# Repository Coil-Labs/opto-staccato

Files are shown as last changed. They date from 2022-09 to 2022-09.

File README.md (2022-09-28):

# opto-staccato

## Introduction
This is a pair of circuit boards (PCBs), known as the Opto-Staccato Controller and Receiver, which are a mains frequency synchronized interrupter for Tesla coils, primarily vacuum tube Tesla coils (VTTCs).

This circuit is based on the original Staccato Controller, created by Steve Ward https://www.stevehv.4hv.org/staccato.htm

This circuit is featured on the Coil Labs YouTube channel and is used to interrupt a large VTTC (https://youtu.be/IDOrxT_r8TY). This project was sponsored in part by PCBgogo (https://www.pcbgogo.com/), who provided the PCBs for this video.

The KiCad source files for both boards are available in this repository and the gerber files for both boards are available as .zip files in the Releases.

## Description

The Controller PCB detects the mains frequency zero crossing and then sends a pulse to the Receiver (with a controllable delay based on potentiometer RV1), signaling when to let the Tesla coil primary circuit to begin conducting. This signal is sent over a fiber optic link to protect the user from coming into contact with high voltage and enabling them to maintain a safe distance from the Tesla coil. The other controllable parameter (set by potentiometer RV2) of the Controller is the interrupter hold-off time, which enables the Tesla coil to be driven at integer factors of the mains frequency (e.g., 60 Hz, 30 Hz, 15 Hz, etc. in North America).

## Safety
WARNING! High voltage electricity and Tesla coils are dangerous and should not be handled or operated by anyone other than trained experts! 

## Usage
Jumpers J5 and J6 on the Controller and J7 and J8 on the Receiver enable using the PCBs in either 120V or 240V mains regions. Place two jumpers across pins 1 and 2 of both jumpers for 120V use or a single jumper across pin 2 of the two jumpers for 240V use, as indicated on the silk screen.

On the Controller, switch SW1 is the "phase-select" choosing to trigger the circuit on either the rising or falling mains zero crossing. Switch Sw2 is the "output-enable" switch, allowing the user to control when the Tesla coil interrupter is "turned on". Switch Sw3 selects the source of the signal being sent out via the fiber optic link; either the Staccato signal, "always on" for continuous wave operation, or an optional external 0-12V digital signal that can be provided via screw terminal J2.

The SCR or TRIAC used for Staccato operation is not included on the Receiver PCB as the choice of this component is specific to each Tesla coil. A screw terminal block J4 is provided to connect to the gate and cathode terminals for triggering. The selection of resistor R22 may need to be changed, depending on the gate voltage and current requirements of the SCR/TRIAC being used.

The fiber optic transmitter and receiver use standard 1000um core, 2.2mm jacket plastic fiber cable. The fuses are 500mA, 250V, fast blow, glass cartridge, 5mm x 20mm.

## License
These design files are published under the CERN Open Hardware License Version 2 - Weakly Reciprocal variant (CERN-OHL-W). Read more here (https://cern.ch/cern-ohl).

This is a copyleft, share-alike, open-source license. This means that you are free to redistribute, modify, or make derivatives these designs, and even commercialize them. But you MUST keep the redistributed, modified, or derivative designs open-source and under this or a compatible license. You CANNOT make modified or derivative designs proprietary; they MUST be kept open-source. This is different than a "permissive" open-source license, where you can make modifications or derivatives proprietary and then commercialize and profit off of your proprietary modification. You are absolutely free to commercialize and profit from modifications of this design, however, it must remain open-source and accessible to the public. Copyleft, share-alike is a philosophy. Scientific and engineering knowledge should not be kept as trade secrets and locked down under patents, owned by the wealthy, to only benefit the wealthy. Knowledge should be freely shared, always. Publishing scientific and engineering works under copyleft, share-alike licenses helps to create a more fair and democratic future where the hoarding of trade secrets is not a way to gain a competitive advantage. Please consider publishing your own works under such a license.

## Controller Schematic
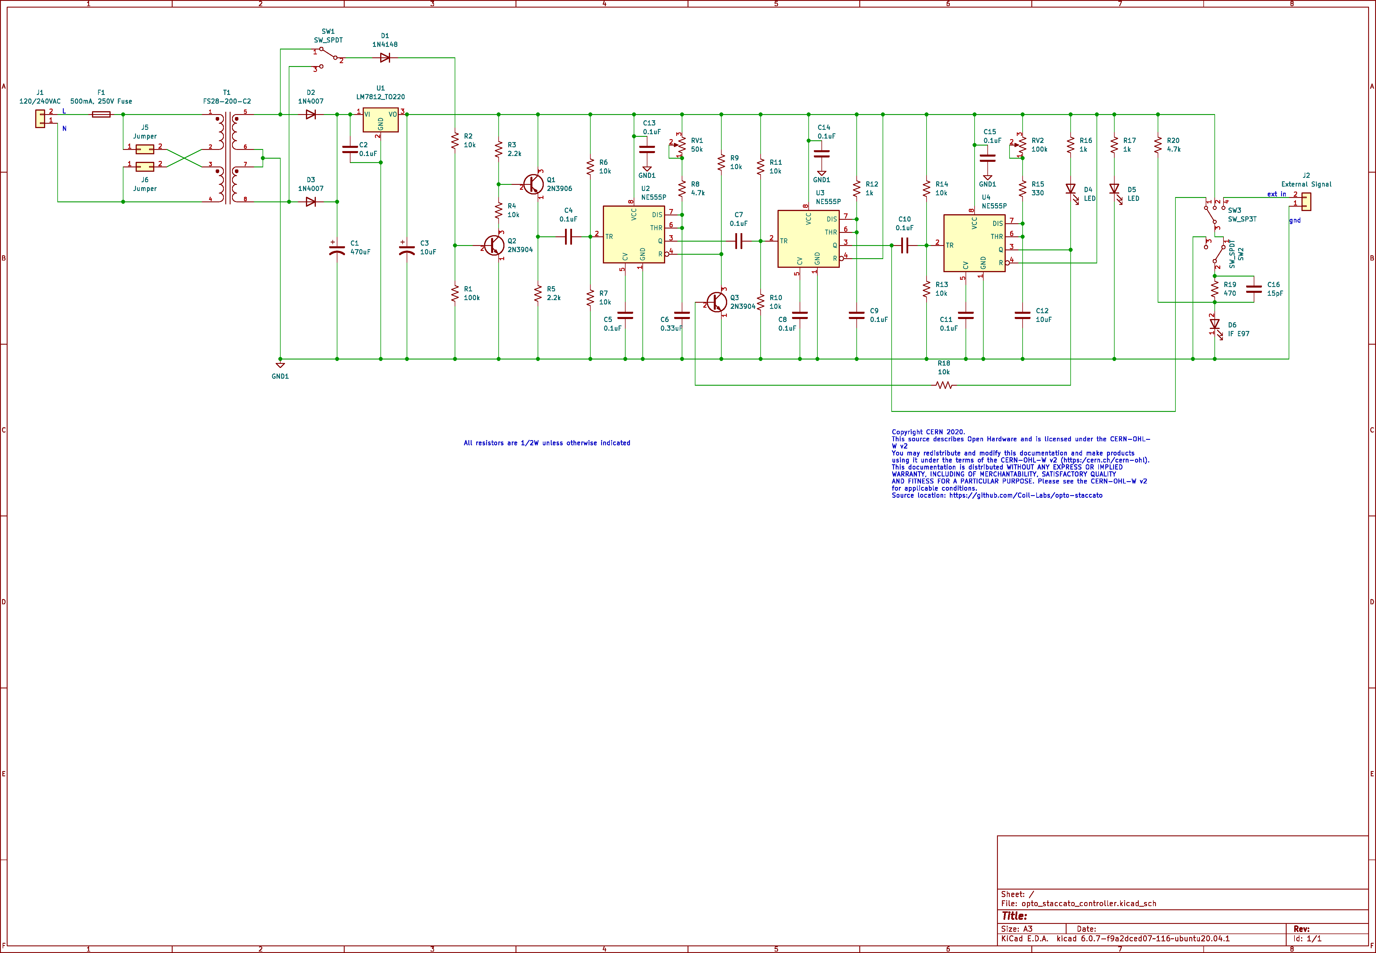
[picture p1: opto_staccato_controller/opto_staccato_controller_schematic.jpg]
Controller Schematic


## Receiver Schematic
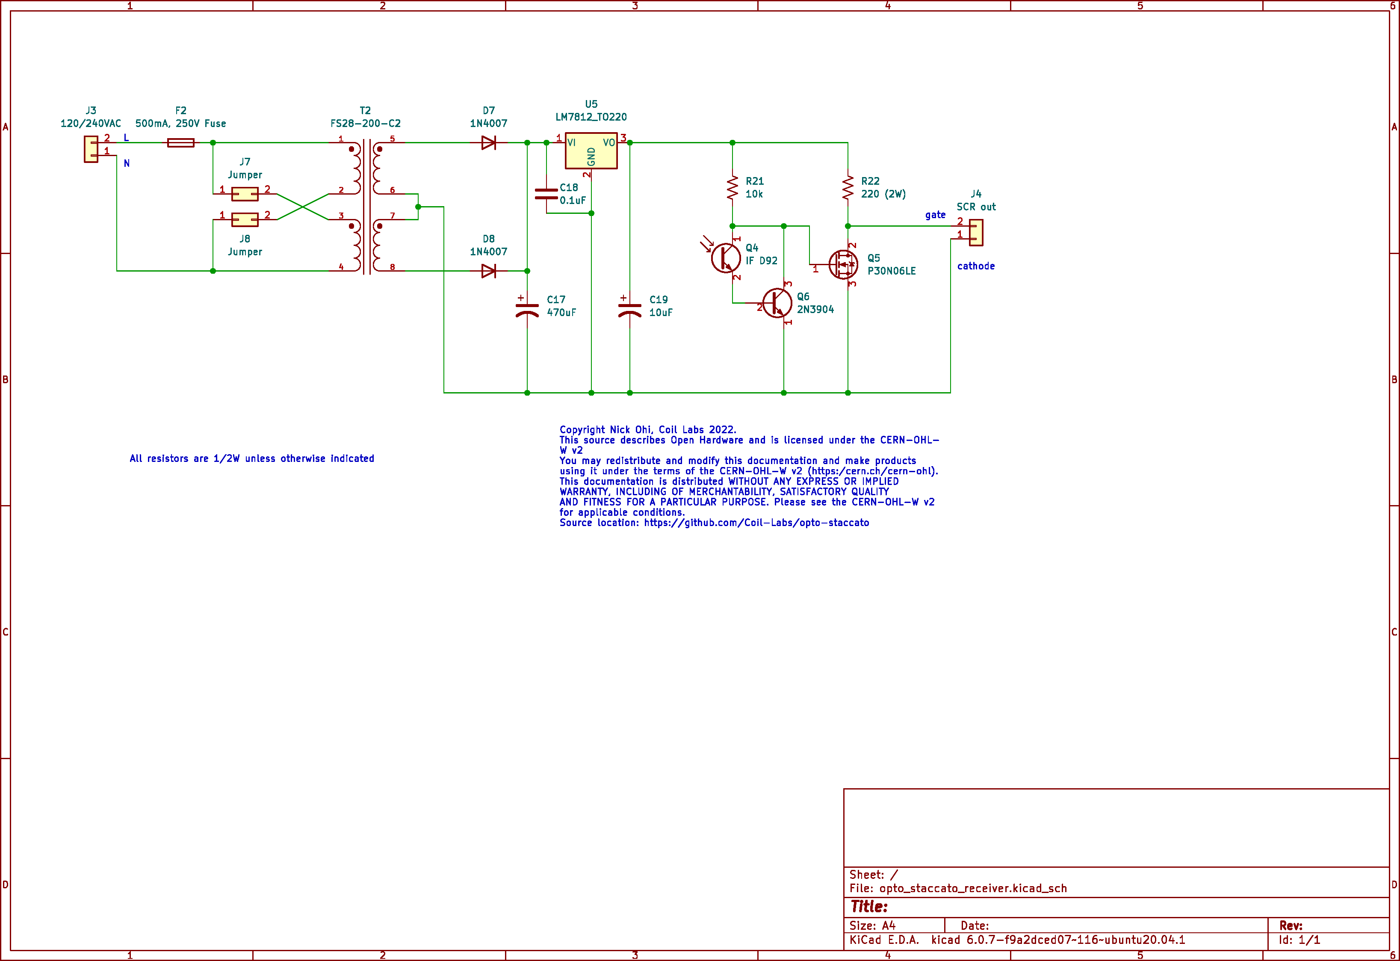
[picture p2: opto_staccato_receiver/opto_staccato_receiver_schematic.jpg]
Receiver Schematic


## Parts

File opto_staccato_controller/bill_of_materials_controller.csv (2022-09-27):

Date: | Mon 26 Sep 2022 07:49:17 PM EDT
Tool: | Eeschema 6.0.7-f9a2dced07~116~ubuntu20.04.1
Component Count: | 60
Individual Components:
Item | Qty | Reference(s) | Value | LibPart | Footprint | Datasheet | MANUFACTURER | STANDARD | Spice_Lib_File | Spice_Model | Spice_Netlist_Enabled | Spice_Primitive
 |  | C1 | 470uF | Device:C_Polarized_US | Capacitor_THT:CP_Radial_D10.0mm_P5.00mm | ~ |  |  |  | 470u | Y | C
 |  | C2 | 0.1uF | Device:C | Capacitor_THT:C_Disc_D4.7mm_W2.5mm_P5.00mm | ~ |  |  |  | 0.1u | Y | C
 |  | C3 | 10uF | Device:C_Polarized_US | Capacitor_THT:CP_Radial_D5.0mm_P2.00mm | ~ |  |  |  | 10u | Y | C
 |  | C4 | 0.1uF | Device:C | Capacitor_THT:C_Disc_D4.7mm_W2.5mm_P5.00mm | ~ |  |  |  | 0.1u | Y | C
 |  | C5 | 0.1uF | Device:C | Capacitor_THT:C_Disc_D4.7mm_W2.5mm_P5.00mm | ~
 |  | C6 | 0.33uF | Device:C | Capacitor_THT:C_Disc_D6.0mm_W4.4mm_P5.00mm | ~
 |  | C7 | 0.1uF | Device:C | Capacitor_THT:C_Disc_D4.7mm_W2.5mm_P5.00mm | ~
 |  | C8 | 0.1uF | Device:C | Capacitor_THT:C_Disc_D4.7mm_W2.5mm_P5.00mm | ~ |  |  |  | 0.1u | Y | C
 |  | C9 | 0.1uF | Device:C | Capacitor_THT:C_Disc_D4.7mm_W2.5mm_P5.00mm | ~ |  |  |  | 0.2u | Y | C
 |  | C10 | 0.1uF | Device:C | Capacitor_THT:C_Disc_D4.7mm_W2.5mm_P5.00mm | ~ |  |  |  | 0.001u | Y | C
 |  | C11 | 0.1uF | Device:C | Capacitor_THT:C_Disc_D4.7mm_W2.5mm_P5.00mm | ~ |  |  |  | 0.1u | Y | C
 |  | C12 | 10uF | Device:C | Capacitor_THT:C_Disc_D5.1mm_W3.2mm_P5.00mm | ~ |  |  |  | 10u | Y | C
 |  | C13 | 0.1uF | Device:C | Capacitor_THT:C_Disc_D4.7mm_W2.5mm_P5.00mm | ~
 |  | C14 | 0.1uF | Device:C | Capacitor_THT:C_Disc_D4.7mm_W2.5mm_P5.00mm | ~
 |  | C15 | 0.1uF | Device:C | Capacitor_THT:C_Disc_D4.7mm_W2.5mm_P5.00mm | ~
 |  | C16 | 15pF | Device:C | Capacitor_THT:C_Disc_D4.7mm_W2.5mm_P5.00mm | ~
 |  | D1 | 1N4148 | Diode:1N4007 | Diode_THT:D_DO-35_SOD27_P7.62mm_Horizontal | http://www.vishay.com/docs/88503/1n4001.pdf |  |  |  | 1N4007 | Y | D
 |  | D2 | 1N4007 | Diode:1N4007 | Diode_THT:D_DO-41_SOD81_P10.16mm_Horizontal | http://www.vishay.com/docs/88503/1n4001.pdf |  |  |  | 1N4007 | Y | D
 |  | D3 | 1N4007 | Diode:1N4007 | Diode_THT:D_DO-41_SOD81_P10.16mm_Horizontal | http://www.vishay.com/docs/88503/1n4001.pdf |  |  |  | 1N4007 | Y | D
 |  | D4 | LED | Device:LED | LED_THT:LED_D5.0mm_Clear | ~ |  |  |  | LED_GENERAL | Y | D
 |  | D5 | LED | Device:LED | LED_THT:LED_D5.0mm_Clear | ~ |  |  |  | LED_GENERAL | Y | D
 |  | D6 | IF E97 | :LED_1 | IF-E91A:IF-E91A | ~
 |  | F1 | 500mA, 250V Fuse | Device:Fuse | 0PTF0078P:0PTF0078P | ~
 |  | J1 | 120/240VAC | Connector_Generic:Conn_01x02 | Connector_Wire:SolderWire-1sqmm_1x02_P5.4mm_D1.4mm_OD2.7mm | ~
 |  | J2 | External Signal | Connector_Generic:Conn_01x02 | TB007-508-02GR:CUI_TB007-508-02GR | ~
 |  | J5 | Jumper | Connector_Generic:Conn_02x01 | Connector_PinHeader_2.54mm:PinHeader_2x01_P2.54mm_Vertical | ~
 |  | J6 | Jumper | Connector_Generic:Conn_02x01 | Connector_PinHeader_2.54mm:PinHeader_2x01_P2.54mm_Vertical | ~
 |  | Q1 | 2N3906 | Transistor_BJT:2N3906 | Package_TO_SOT_THT:TO-92_Inline | https://www.onsemi.com/pub/Collateral/2N3906-D.PDF |  |  |  | 2N3906 | Y | Q
 |  | Q2 | 2N3904 | Transistor_BJT:2N3904 | Package_TO_SOT_THT:TO-92_Inline | https://www.onsemi.com/pub/Collateral/2N3903-D.PDF |  |  |  | 2N3904 | Y | Q
 |  | Q3 | 2N3904 | Transistor_BJT:2N3904 | Package_TO_SOT_THT:TO-92_Inline | https://www.onsemi.com/pub/Collateral/2N3903-D.PDF |  |  |  | 2N3904 | Y | Q
 |  | R1 | 100k | Device:R_US | Resistor_THT:R_Axial_DIN0309_L9.0mm_D3.2mm_P12.70mm_Horizontal | ~ |  |  |  | 100k | Y | R
 |  | R2 | 10k | Device:R_US | Resistor_THT:R_Axial_DIN0309_L9.0mm_D3.2mm_P12.70mm_Horizontal | ~ |  |  |  | 10k | Y | R
 |  | R3 | 2.2k | Device:R_US | Resistor_THT:R_Axial_DIN0309_L9.0mm_D3.2mm_P12.70mm_Horizontal | ~ |  |  |  | 2.2k | Y | R
 |  | R4 | 10k | Device:R_US | Resistor_THT:R_Axial_DIN0309_L9.0mm_D3.2mm_P12.70mm_Horizontal | ~ |  |  |  | 10k | Y | R
 |  | R5 | 2.2k | Device:R_US | Resistor_THT:R_Axial_DIN0309_L9.0mm_D3.2mm_P12.70mm_Horizontal | ~ |  |  |  | 2.2k | Y | R
 |  | R6 | 10k | Device:R_US | Resistor_THT:R_Axial_DIN0309_L9.0mm_D3.2mm_P12.70mm_Horizontal | ~ |  |  |  | 100k | Y | R
 |  | R7 | 10k | Device:R_US | Resistor_THT:R_Axial_DIN0309_L9.0mm_D3.2mm_P12.70mm_Horizontal | ~ |  |  |  | 100k | Y | R
 |  | R8 | 4.7k | Device:R_US | Resistor_THT:R_Axial_DIN0309_L9.0mm_D3.2mm_P12.70mm_Horizontal | ~
 |  | R9 | 10k | Device:R_US | Resistor_THT:R_Axial_DIN0309_L9.0mm_D3.2mm_P12.70mm_Horizontal | ~ |  |  |  | 10k | Y | R
 |  | R10 | 10k | Device:R_US | Resistor_THT:R_Axial_DIN0309_L9.0mm_D3.2mm_P12.70mm_Horizontal | ~
 |  | R11 | 10k | Device:R_US | Resistor_THT:R_Axial_DIN0309_L9.0mm_D3.2mm_P12.70mm_Horizontal | ~
 |  | R12 | 1k | Device:R_US | Resistor_THT:R_Axial_DIN0309_L9.0mm_D3.2mm_P12.70mm_Horizontal | ~ |  |  |  | 1k | Y | R
 |  | R13 | 10k | Device:R_US | Resistor_THT:R_Axial_DIN0309_L9.0mm_D3.2mm_P12.70mm_Horizontal | ~ |  |  |  | 10k | Y | R
 |  | R14 | 10k | Device:R_US | Resistor_THT:R_Axial_DIN0309_L9.0mm_D3.2mm_P12.70mm_Horizontal | ~ |  |  |  | 10k | Y | R
 |  | R15 | 330 | Device:R_US | Resistor_THT:R_Axial_DIN0309_L9.0mm_D3.2mm_P12.70mm_Horizontal | ~ |  |  |  | 1k | Y | R
 |  | R16 | 1k | Device:R_US | Resistor_THT:R_Axial_DIN0309_L9.0mm_D3.2mm_P12.70mm_Horizontal | ~ |  |  |  | 1k | Y | R
 |  | R17 | 1k | Device:R_US | Resistor_THT:R_Axial_DIN0309_L9.0mm_D3.2mm_P12.70mm_Horizontal | ~ |  |  |  | 1k | Y | R
 |  | R18 | 10k | Device:R_US | Resistor_THT:R_Axial_DIN0309_L9.0mm_D3.2mm_P12.70mm_Horizontal | ~ |  |  |  | 10k | Y | R
 |  | R19 | 470 | Device:R_US | Resistor_THT:R_Axial_DIN0309_L9.0mm_D3.2mm_P12.70mm_Horizontal | ~
 |  | R20 | 4.7k | Device:R_US | Resistor_THT:R_Axial_DIN0309_L9.0mm_D3.2mm_P12.70mm_Horizontal | ~ |  |  |  | 1k | Y | R
 |  | RV1 | 50k | Device:R_Potentiometer_US | Connector_Wire:SolderWire-0.5sqmm_1x03_P4.6mm_D0.9mm_OD2.1mm | ~
 |  | RV2 | 100k | Device:R_Potentiometer_US | Connector_Wire:SolderWire-0.5sqmm_1x03_P4.6mm_D0.9mm_OD2.1mm | ~ |  |  |  | pot50k | Y | X
 |  | SW1 | SW_SPDT | Switch:SW_SPDT | Connector_Wire:SolderWire-0.5sqmm_1x03_P4.6mm_D0.9mm_OD2.1mm | ~
 |  | SW2 | SW_SPDT | Switch:SW_SPDT | Connector_Wire:SolderWire-0.5sqmm_1x03_P4.6mm_D0.9mm_OD2.1mm | ~
 |  | SW3 | SW_SP3T | Switch:SW_SP3T | Connector_Wire:SolderWire-0.5sqmm_1x04_P4.6mm_D0.9mm_OD2.1mm | ~
 |  | T1 | FS28-200-C2 | FS28-200-C2:FS28-200-C2 | FS28-200-C2:TRANSFORMER_FS28-200-C2 |  | Triad | Manufacturer Recommendations
 |  | U1 | LM7812_TO220 | Regulator_Linear:LM7812_TO220 | Package_TO_SOT_THT:TO-220-3_Vertical | https://www.onsemi.cn/PowerSolutions/document/MC7800-D.PDF |  |  |  | LM7812 | Y | X
 |  | U2 | NE555P | Timer:NE555P | Package_DIP:DIP-8_W7.62mm | http://www.ti.com/lit/ds/symlink/ne555.pdf |  |  |  | NE555 | Y | X
 |  | U3 | NE555P | Timer:NE555P | Package_DIP:DIP-8_W7.62mm | http://www.ti.com/lit/ds/symlink/ne555.pdf |  |  |  | NE555 | Y | X
 |  | U4 | NE555P | Timer:NE555P | Package_DIP:DIP-8_W7.62mm | http://www.ti.com/lit/ds/symlink/ne555.pdf |  |  |  | NE555 | Y | X
Collated Components:
Item | Qty | Reference(s) | Value | LibPart | Footprint | Datasheet | MANUFACTURER | STANDARD | Spice_Lib_File | Spice_Model | Spice_Netlist_Enabled | Spice_Primitive
1 | 1 | C1 | 470uF | Device:C_Polarized_US | Capacitor_THT:CP_Radial_D10.0mm_P5.00mm | ~ |  |  |  | 470u | Y | C
2 | 11 | C2, C4, C5, C7, C8, C9, C10, C11, C13, C14, C15 | 0.1uF | Device:C | Capacitor_THT:C_Disc_D4.7mm_W2.5mm_P5.00mm | ~ |  |  |  | 0.1u | Y | C
3 | 1 | C3 | 10uF | Device:C_Polarized_US | Capacitor_THT:CP_Radial_D5.0mm_P2.00mm | ~ |  |  |  | 10u | Y | C
4 | 1 | C6 | 0.33uF | Device:C | Capacitor_THT:C_Disc_D6.0mm_W4.4mm_P5.00mm | ~
5 | 1 | C12 | 10uF | Device:C | Capacitor_THT:C_Disc_D5.1mm_W3.2mm_P5.00mm | ~ |  |  |  | 10u | Y | C
6 | 1 | C16 | 15pF | Device:C | Capacitor_THT:C_Disc_D4.7mm_W2.5mm_P5.00mm | ~
7 | 1 | D1 | 1N4148 | Diode:1N4007 | Diode_THT:D_DO-35_SOD27_P7.62mm_Horizontal | http://www.vishay.com/docs/88503/1n4001.pdf |  |  | /media/nick/3TB_HDD/College Documents/Personal/Coil Labs Files/kicad_spice_library/Models/Diode/DIODE2.lib | 1N4007 | Y | D
8 | 2 | D2, D3 | 1N4007 | Diode:1N4007 | Diode_THT:D_DO-41_SOD81_P10.16mm_Horizontal | http://www.vishay.com/docs/88503/1n4001.pdf |  |  | /media/nick/3TB_HDD/College Documents/Personal/Coil Labs Files/kicad_spice_library/Models/Diode/DIODE2.lib | 1N4007 | Y | D
9 | 2 | D4, D5 | LED | Device:LED | LED_THT:LED_D5.0mm_Clear | ~ |  |  | /media/nick/3TB_HDD/College Documents/Personal/Coil Labs Files/kicad_spice_library/Models/Diode/led.lib | LED_GENERAL | Y | D
10 | 1 | D6 | IF E97 | :LED_1 | IF-E91A:IF-E91A | ~
11 | 1 | F1 | 500mA, 250V Fuse | Device:Fuse | 0PTF0078P:0PTF0078P | ~
12 | 1 | J1 | 120/240VAC | Connector_Generic:Conn_01x02 | Connector_Wire:SolderWire-1sqmm_1x02_P5.4mm_D1.4mm_OD2.7mm | ~
13 | 1 | J2 | External Signal | Connector_Generic:Conn_01x02 | TB007-508-02GR:CUI_TB007-508-02GR | ~
14 | 2 | J5, J6 | Jumper | Connector_Generic:Conn_02x01 | Connector_PinHeader_2.54mm:PinHeader_2x01_P2.54mm_Vertical | ~
15 | 1 | Q1 | 2N3906 | Transistor_BJT:2N3906 | Package_TO_SOT_THT:TO-92_Inline | https://www.onsemi.com/pub/Collateral/2N3906-D.PDF |  |  | /media/nick/3TB_HDD/College Documents/Personal/Coil Labs Files/kicad_spice_library/Models/Transistor/BJT/BJT.lib | 2N3906 | Y | Q
16 | 2 | Q2, Q3 | 2N3904 | Transistor_BJT:2N3904 | Package_TO_SOT_THT:TO-92_Inline | https://www.onsemi.com/pub/Collateral/2N3903-D.PDF |  |  | /media/nick/3TB_HDD/College Documents/Personal/Coil Labs Files/kicad_spice_library/Models/Transistor/BJT/BJT.lib | 2N3904 | Y | Q
17 | 1 | R1 | 100k | Device:R_US | Resistor_THT:R_Axial_DIN0309_L9.0mm_D3.2mm_P12.70mm_Horizontal | ~ |  |  |  | 100k | Y | R
18 | 10 | R2, R4, R6, R7, R9, R10, R11, R13, R14, R18 | 10k | Device:R_US | Resistor_THT:R_Axial_DIN0309_L9.0mm_D3.2mm_P12.70mm_Horizontal | ~ |  |  |  | 10k | Y | R
19 | 2 | R3, R5 | 2.2k | Device:R_US | Resistor_THT:R_Axial_DIN0309_L9.0mm_D3.2mm_P12.70mm_Horizontal | ~ |  |  |  | 2.2k | Y | R
20 | 2 | R8, R20 | 4.7k | Device:R_US | Resistor_THT:R_Axial_DIN0309_L9.0mm_D3.2mm_P12.70mm_Horizontal | ~ |  |  |  | 1k | Y | R
21 | 3 | R12, R16, R17 | 1k | Device:R_US | Resistor_THT:R_Axial_DIN0309_L9.0mm_D3.2mm_P12.70mm_Horizontal | ~ |  |  |  | 1k | Y | R
22 | 1 | R15 | 330 | Device:R_US | Resistor_THT:R_Axial_DIN0309_L9.0mm_D3.2mm_P12.70mm_Horizontal | ~ |  |  |  | 1k | Y | R
23 | 1 | R19 | 470 | Device:R_US | Resistor_THT:R_Axial_DIN0309_L9.0mm_D3.2mm_P12.70mm_Horizontal | ~
24 | 1 | RV1 | 50k | Device:R_Potentiometer_US | Connector_Wire:SolderWire-0.5sqmm_1x03_P4.6mm_D0.9mm_OD2.1mm | ~
25 | 1 | RV2 | 100k | Device:R_Potentiometer_US | Connector_Wire:SolderWire-0.5sqmm_1x03_P4.6mm_D0.9mm_OD2.1mm | ~ |  |  | /media/nick/3TB_HDD/College Documents/Personal/Coil Labs Files/kicad_basic_models/others/50kpot.lib | pot50k | Y | X
26 | 2 | SW1, SW2 | SW_SPDT | Switch:SW_SPDT | Connector_Wire:SolderWire-0.5sqmm_1x03_P4.6mm_D0.9mm_OD2.1mm | ~
27 | 1 | SW3 | SW_SP3T | Switch:SW_SP3T | Connector_Wire:SolderWire-0.5sqmm_1x04_P4.6mm_D0.9mm_OD2.1mm | ~
28 | 1 | T1 | FS28-200-C2 | FS28-200-C2:FS28-200-C2 | FS28-200-C2:TRANSFORMER_FS28-200-C2 |  | Triad | Manufacturer Recommendations
29 | 1 | U1 | LM7812_TO220 | Regulator_Linear:LM7812_TO220 | Package_TO_SOT_THT:TO-220-3_Vertical | https://www.onsemi.cn/PowerSolutions/document/MC7800-D.PDF |  |  | /media/nick/3TB_HDD/College Documents/Personal/Coil Labs Files/kicad_spice_library/Models/uncategorized/Bordodynovs Electronics Lib/sub/regulators.lib | LM7812 | Y | X
30 | 3 | U2, U3, U4 | NE555P | Timer:NE555P | Package_DIP:DIP-8_W7.62mm | http://www.ti.com/lit/ds/symlink/ne555.pdf |  |  | /media/nick/3TB_HDD/College Documents/Personal/Coil Labs Files/kicad_spice_library/Models/uncategorized/Bordodynovs Electronics Lib/sub/timers.lib | NE555 | Y | X

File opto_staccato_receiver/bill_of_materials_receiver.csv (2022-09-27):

Date: | Mon 26 Sep 2022 07:53:28 PM EDT
Tool: | Eeschema 6.0.7-f9a2dced07~116~ubuntu20.04.1
Component Count: | 17
Individual Components:
Item | Qty | Reference(s) | Value | LibPart | Footprint | Datasheet | MANUFACTURER | STANDARD | Spice_Lib_File | Spice_Model | Spice_Netlist_Enabled | Spice_Primitive
 |  | C17 | 470uF | Device:C_Polarized_US | Capacitor_THT:CP_Radial_D10.0mm_P5.00mm | ~ |  |  |  | 470u | Y | C
 |  | C18 | 0.1uF | Device:C | Capacitor_THT:C_Disc_D4.7mm_W2.5mm_P5.00mm | ~ |  |  |  | 0.1u | Y | C
 |  | C19 | 10uF | Device:C_Polarized_US | Capacitor_THT:CP_Radial_D5.0mm_P2.00mm | ~ |  |  |  | 10u | Y | C
 |  | D7 | 1N4007 | Diode:1N4007 | Diode_THT:D_DO-41_SOD81_P10.16mm_Horizontal | http://www.vishay.com/docs/88503/1n4001.pdf |  |  |  | 1N4007 | Y | D
 |  | D8 | 1N4007 | Diode:1N4007 | Diode_THT:D_DO-41_SOD81_P10.16mm_Horizontal | http://www.vishay.com/docs/88503/1n4001.pdf |  |  |  | 1N4007 | Y | D
 |  | F2 | 500mA, 250V Fuse | Device:Fuse | 0PTF0078P:0PTF0078P | ~
 |  | J3 | 120/240VAC | Connector_Generic:Conn_01x02 | Connector_Wire:SolderWire-1sqmm_1x02_P5.4mm_D1.4mm_OD2.7mm | ~
 |  | J4 | SCR out | Connector_Generic:Conn_01x02 | TB007-508-02GR:CUI_TB007-508-02GR | ~
 |  | J7 | Jumper | Connector_Generic:Conn_02x01 | Connector_PinHeader_2.54mm:PinHeader_2x01_P2.54mm_Vertical | ~
 |  | J8 | Jumper | Connector_Generic:Conn_02x01 | Connector_PinHeader_2.54mm:PinHeader_2x01_P2.54mm_Vertical | ~
 |  | Q4 | IF D92 | Device:Q_Photo_NPN | IF-E91A:IF-E91A | ~
 |  | Q5 | P30N06LE | Device:Q_NMOS_GDS | Package_TO_SOT_THT:TO-220-3_Vertical | ~
 |  | Q6 | 2N3904 | Transistor_BJT:2N3904 | Package_TO_SOT_THT:TO-92_Inline | https://www.onsemi.com/pub/Collateral/2N3903-D.PDF |  |  |  | 2N3904 | Y | Q
 |  | R21 | 10k | Device:R_US | Resistor_THT:R_Axial_DIN0309_L9.0mm_D3.2mm_P12.70mm_Horizontal | ~
 |  | R22 | 220 (2W) | Device:R_US | Resistor_THT:R_Axial_DIN0516_L15.5mm_D5.0mm_P20.32mm_Horizontal | ~
 |  | T2 | FS28-200-C2 | FS28-200-C2:FS28-200-C2 | FS28-200-C2:TRANSFORMER_FS28-200-C2 |  | Triad | Manufacturer Recommendations
 |  | U5 | LM7812_TO220 | Regulator_Linear:LM7812_TO220 | Package_TO_SOT_THT:TO-220-3_Vertical | https://www.onsemi.cn/PowerSolutions/document/MC7800-D.PDF |  |  |  | LM7812 | Y | X
Collated Components:
Item | Qty | Reference(s) | Value | LibPart | Footprint | Datasheet | MANUFACTURER | STANDARD |  | Spice_Model | Spice_Netlist_Enabled | Spice_Primitive
1 | 1 | C17 | 470uF | Device:C_Polarized_US | Capacitor_THT:CP_Radial_D10.0mm_P5.00mm | ~ |  |  |  | 470u | Y | C
2 | 1 | C18 | 0.1uF | Device:C | Capacitor_THT:C_Disc_D4.7mm_W2.5mm_P5.00mm | ~ |  |  |  | 0.1u | Y | C
3 | 1 | C19 | 10uF | Device:C_Polarized_US | Capacitor_THT:CP_Radial_D5.0mm_P2.00mm | ~ |  |  |  | 10u | Y | C
4 | 2 | D7, D8 | 1N4007 | Diode:1N4007 | Diode_THT:D_DO-41_SOD81_P10.16mm_Horizontal | http://www.vishay.com/docs/88503/1n4001.pdf |  |  |  | 1N4007 | Y | D
5 | 1 | F2 | 500mA, 250V Fuse | Device:Fuse | 0PTF0078P:0PTF0078P | ~
6 | 1 | J3 | 120/240VAC | Connector_Generic:Conn_01x02 | Connector_Wire:SolderWire-1sqmm_1x02_P5.4mm_D1.4mm_OD2.7mm | ~
7 | 1 | J4 | SCR out | Connector_Generic:Conn_01x02 | TB007-508-02GR:CUI_TB007-508-02GR | ~
8 | 2 | J7, J8 | Jumper | Connector_Generic:Conn_02x01 | Connector_PinHeader_2.54mm:PinHeader_2x01_P2.54mm_Vertical | ~
9 | 1 | Q4 | IF D92 | Device:Q_Photo_NPN | IF-E91A:IF-E91A | ~
10 | 1 | Q5 | P30N06LE | Device:Q_NMOS_GDS | Package_TO_SOT_THT:TO-220-3_Vertical | ~
11 | 1 | Q6 | 2N3904 | Transistor_BJT:2N3904 | Package_TO_SOT_THT:TO-92_Inline | https://www.onsemi.com/pub/Collateral/2N3903-D.PDF |  |  |  | 2N3904 | Y | Q
12 | 1 | R21 | 10k | Device:R_US | Resistor_THT:R_Axial_DIN0309_L9.0mm_D3.2mm_P12.70mm_Horizontal | ~
13 | 1 | R22 | 220 (2W) | Device:R_US | Resistor_THT:R_Axial_DIN0516_L15.5mm_D5.0mm_P20.32mm_Horizontal | ~
14 | 1 | T2 | FS28-200-C2 | FS28-200-C2:FS28-200-C2 | FS28-200-C2:TRANSFORMER_FS28-200-C2 |  | Triad | Manufacturer Recommendations
15 | 1 | U5 | LM7812_TO220 | Regulator_Linear:LM7812_TO220 | Package_TO_SOT_THT:TO-220-3_Vertical | https://www.onsemi.cn/PowerSolutions/document/MC7800-D.PDF |  |  |  | LM7812 | Y | X

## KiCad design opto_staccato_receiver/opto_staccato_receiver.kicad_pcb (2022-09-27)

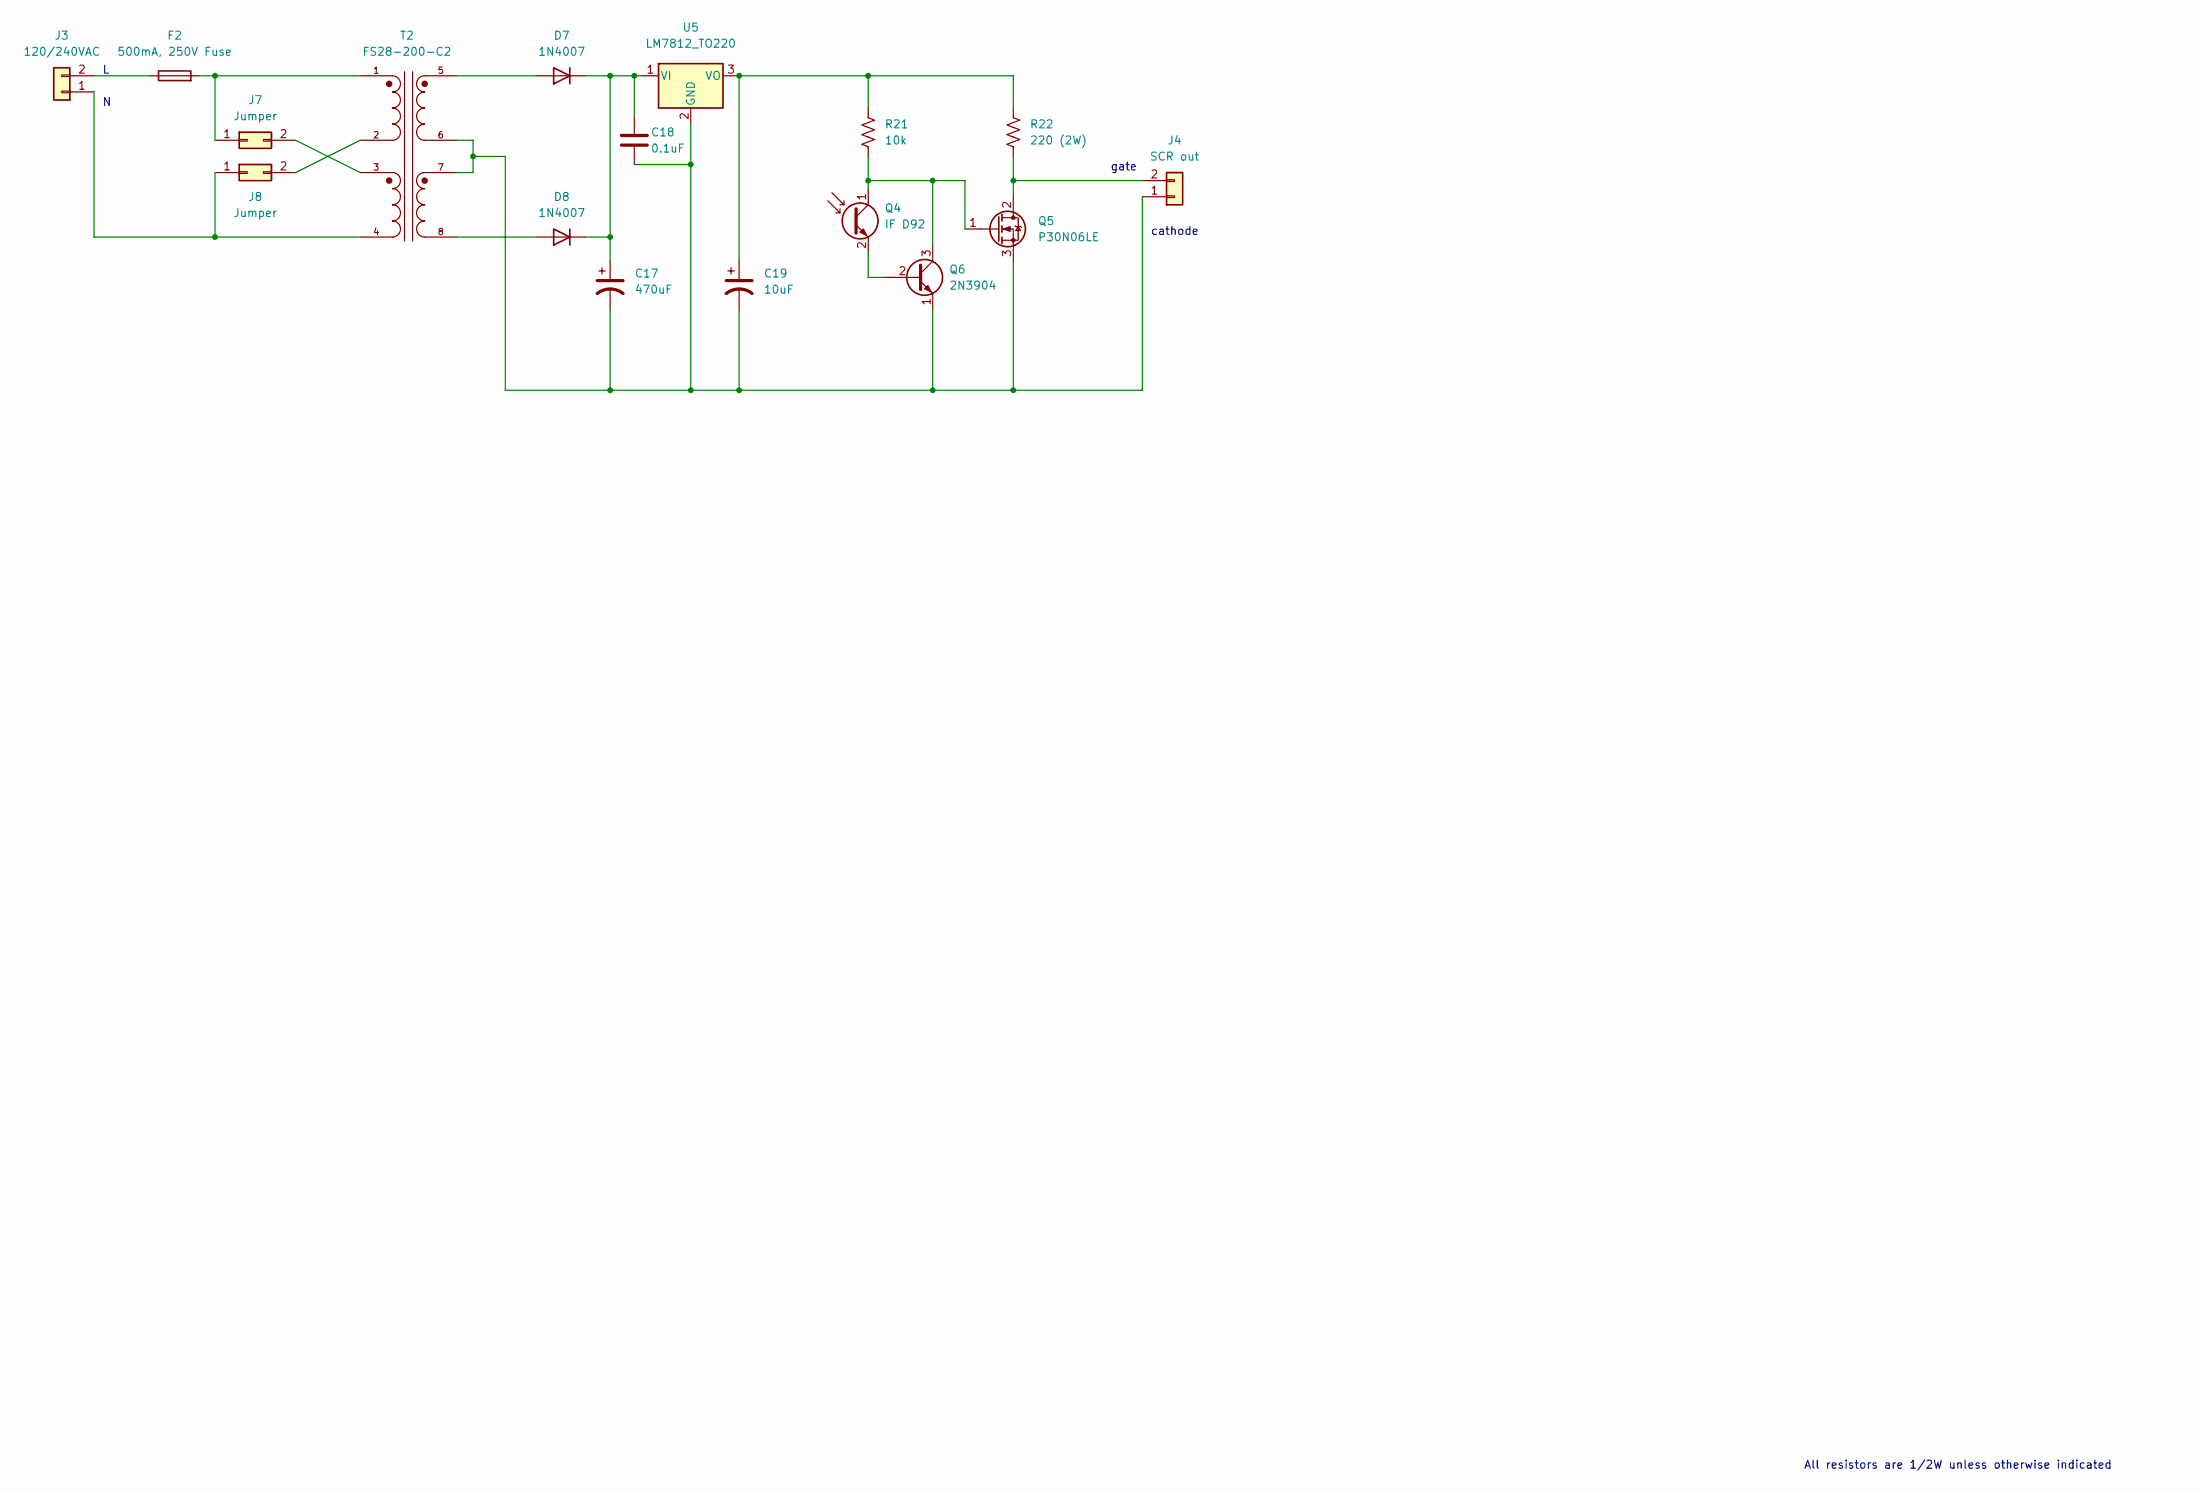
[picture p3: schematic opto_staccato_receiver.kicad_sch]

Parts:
C17: 470uF; CP_Radial_D10.0mm_P5.00mm
C18: 0.1uF; C_Disc_D4.7mm_W2.5mm_P5.00mm
C19: 10uF; CP_Radial_D5.0mm_P2.00mm
D7, D8: 1N4007; D_DO-41_SOD81_P10.16mm_Horizontal
F2: 500mA, 250V Fuse; 0PTF0078P
J3: 120/240VAC; SolderWire-1sqmm_1x02_P5.4mm_D1.4mm_OD2.7mm
J4: SCR out; CUI_TB007-508-02GR
J7, J8: Jumper; PinHeader_2x01_P2.54mm_Vertical
Q4: IF D92; IF-E91A
Q5: P30N06LE; TO-220-3_Vertical
Q6: 2N3904; TO-92_Inline
R21: 10k; R_Axial_DIN0309_L9.0mm_D3.2mm_P12.70mm_Horizontal
R22: 220 (2W); R_Axial_DIN0516_L15.5mm_D5.0mm_P20.32mm_Horizontal
T2: FS28-200-C2; TRANSFORMER_FS28-200-C2
U5: LM7812_TO220; TO-220-3_Vertical

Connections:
unnamed: C17.1, C18.1, D7.1 (K), D8.1 (K), U5.1 (VI)
unnamed: C17.2, C18.2, C19.2, J4.1, Q5.3 (S), Q6.1 (E), T2.6, T2.7, U5.2 (GND)
unnamed: C19.1, R21.1, R22.1, U5.3 (VO)
unnamed: D7.2 (A), T2.5
unnamed: D8.2 (A), T2.8
unnamed: F2.1, J3.2
unnamed: F2.2, J7.1, T2.1
unnamed: J3.1, J8.1, T2.4
unnamed: J4.2, Q5.2 (D), R22.2
unnamed: J7.2, T2.3
unnamed: J8.2, T2.2
unnamed: Q4.1 (C), Q5.1 (G), Q6.3 (C), R21.2
unnamed: Q4.2 (E), Q6.2 (B)

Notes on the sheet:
gate
cathode
All resistors are 1/2W unless otherwise indicated

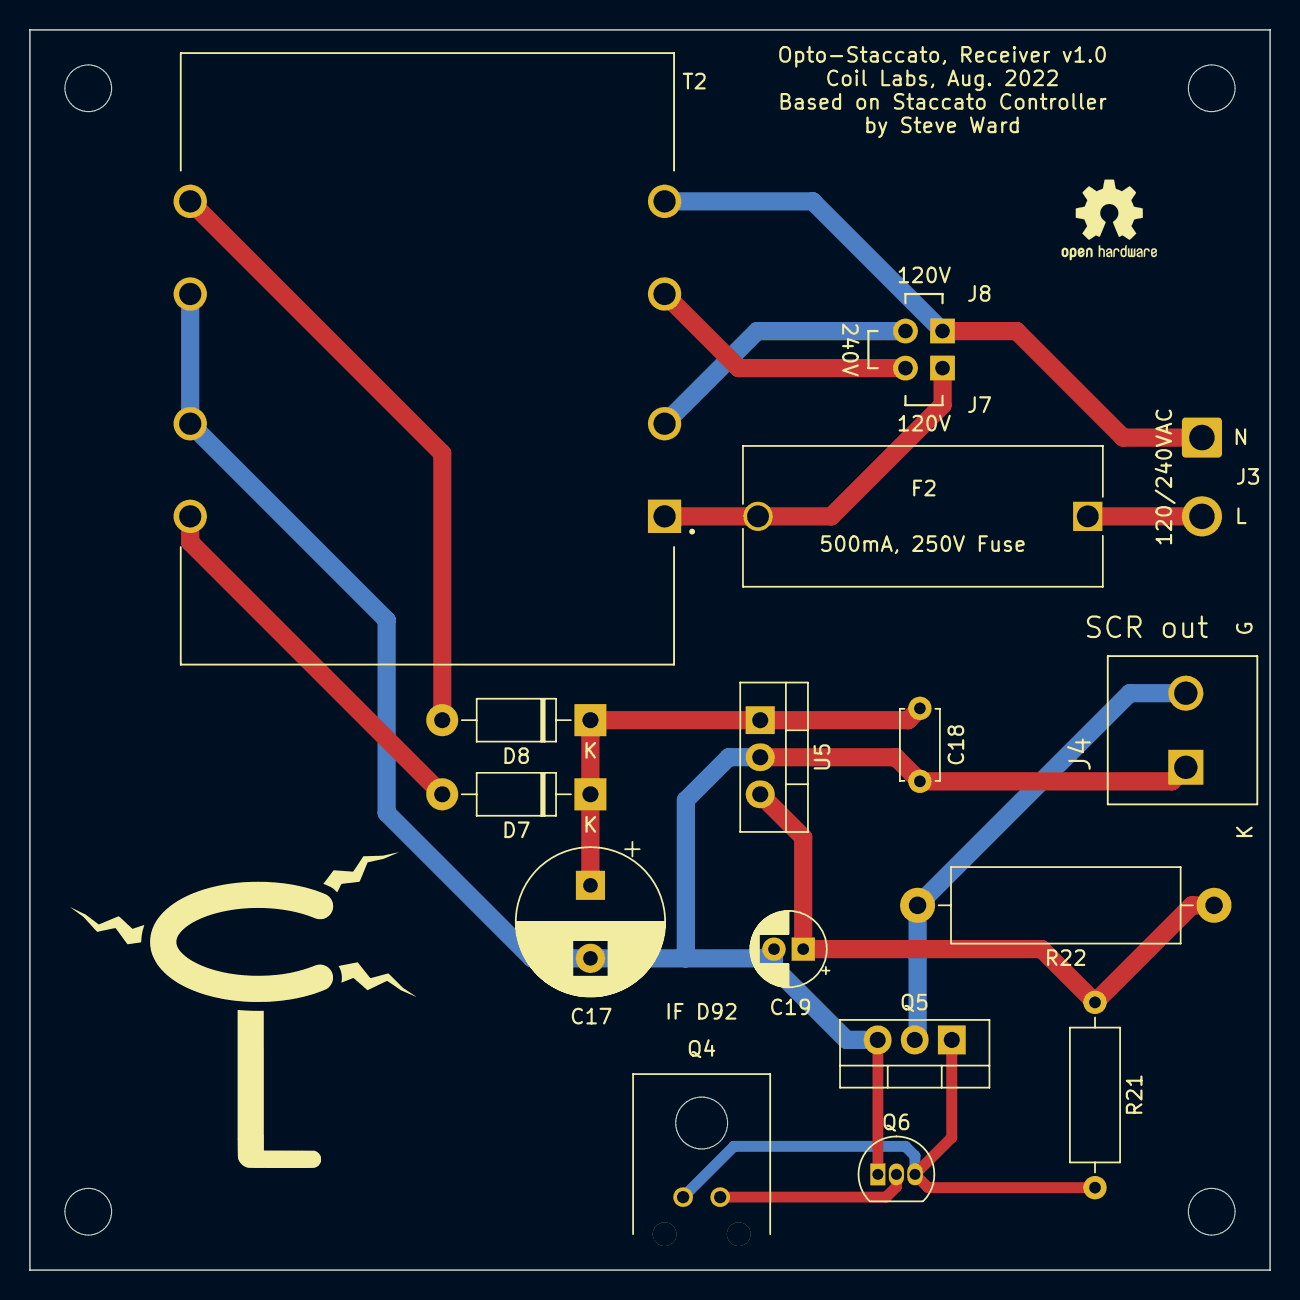
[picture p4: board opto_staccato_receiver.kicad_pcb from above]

Board: 2 copper layers, 85.0 x 85.0 mm, 17 parts (0 on the bottom side), 13 nets.

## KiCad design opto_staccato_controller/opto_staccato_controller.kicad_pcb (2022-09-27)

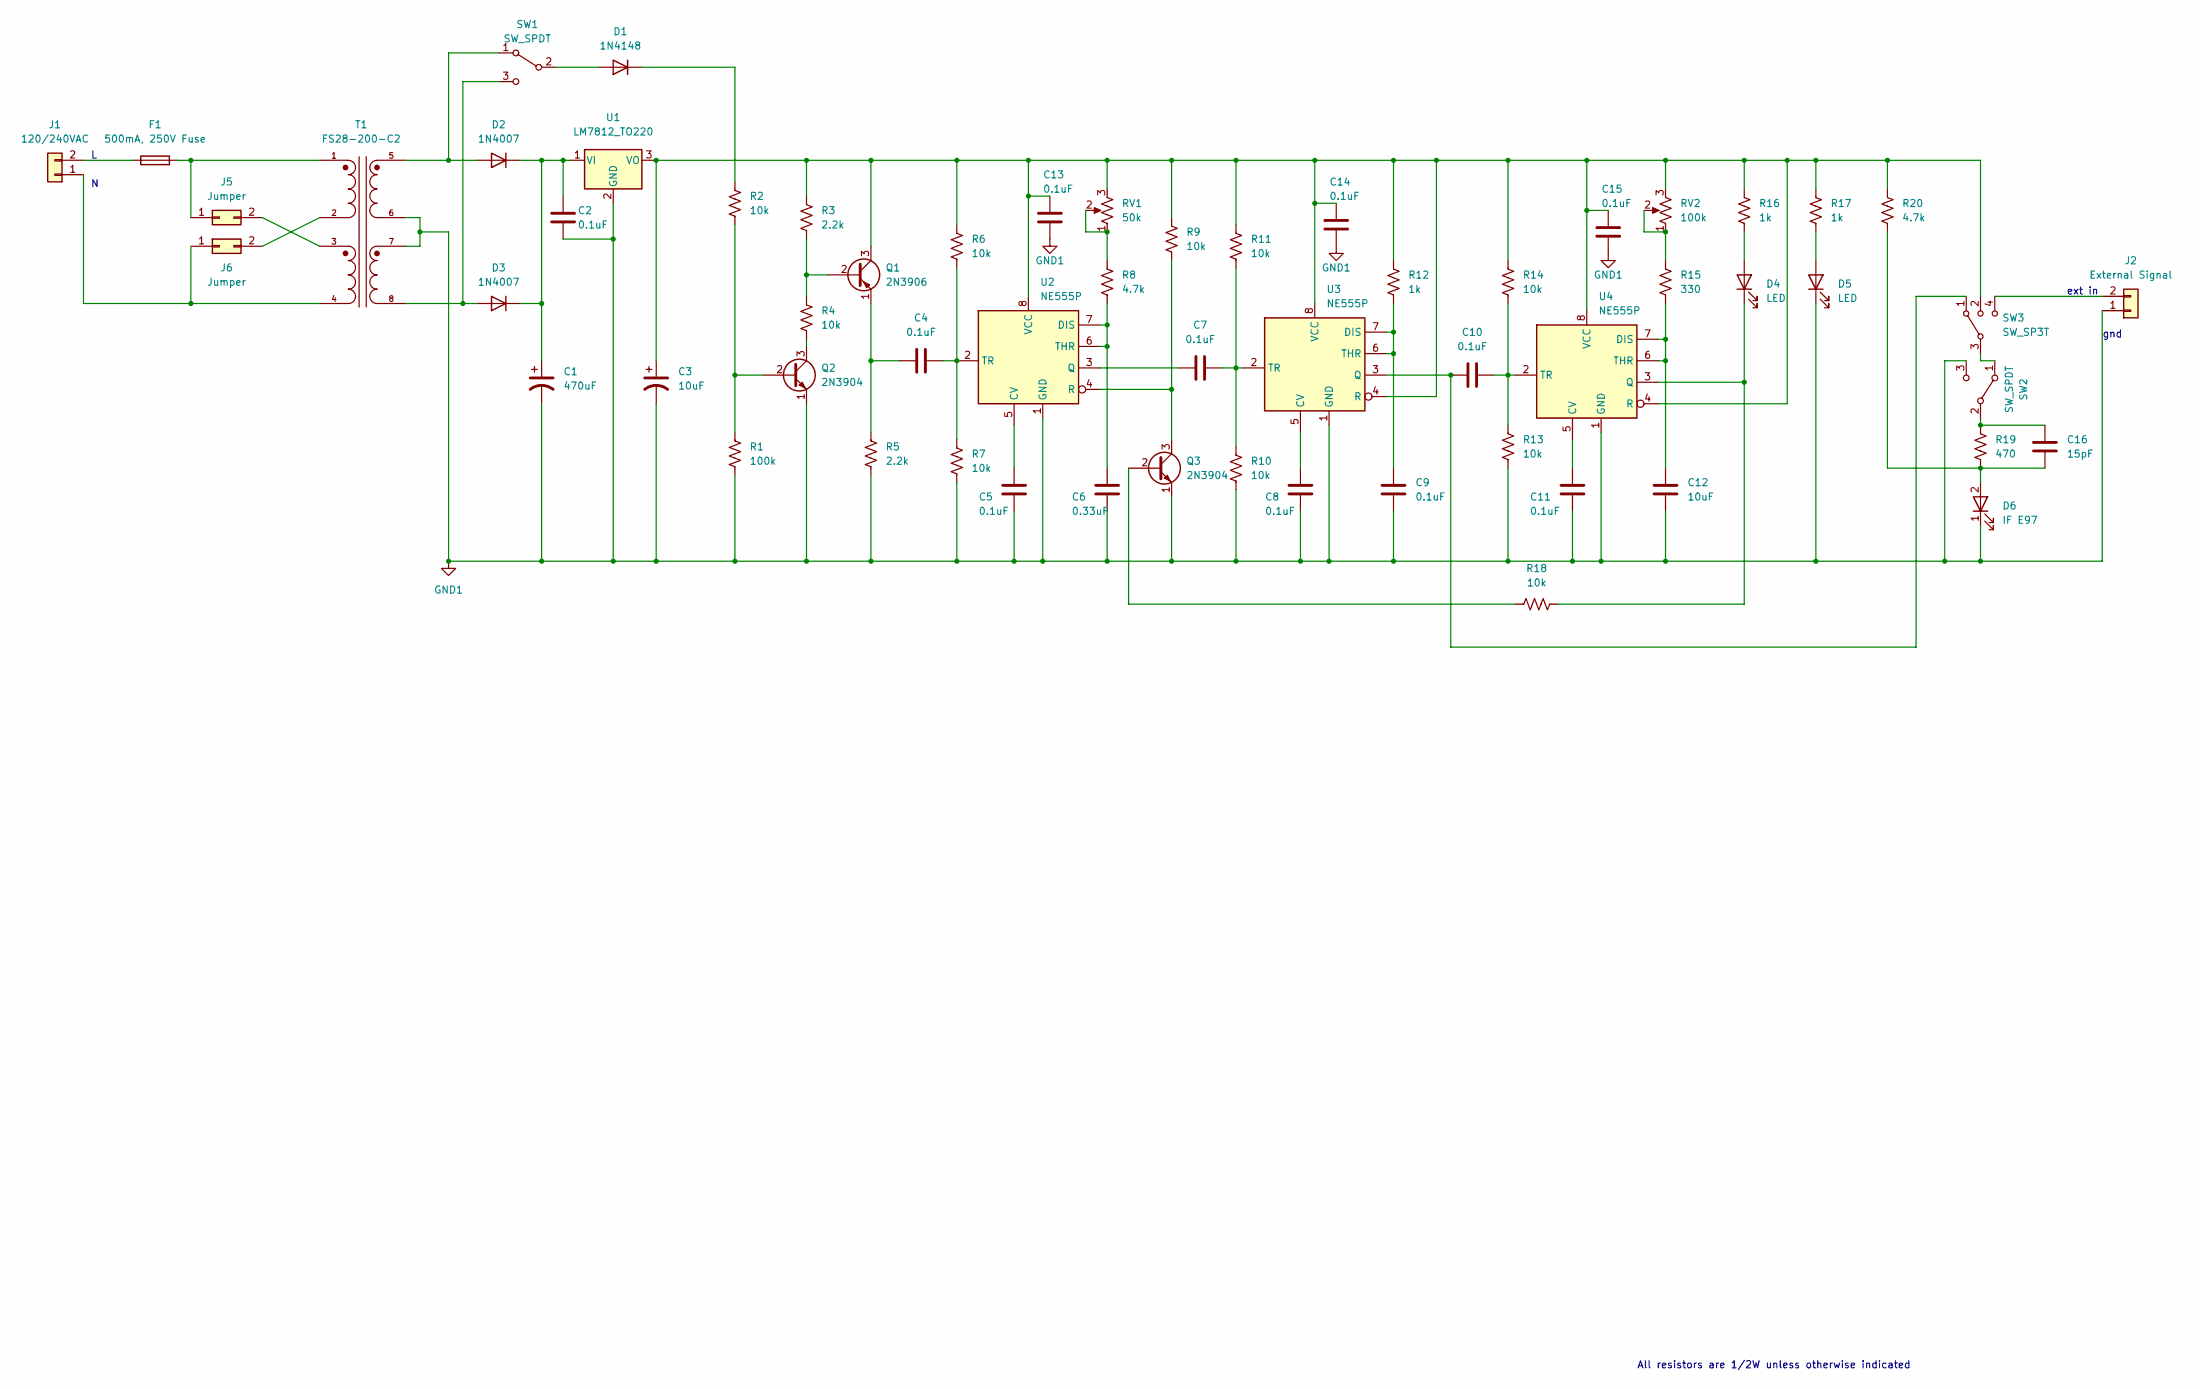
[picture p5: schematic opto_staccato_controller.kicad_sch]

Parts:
C1: 470uF; CP_Radial_D10.0mm_P5.00mm
C2, C4, C5, C7, C8, C9, C10, C11, C13, C14, C15: 0.1uF; C_Disc_D4.7mm_W2.5mm_P5.00mm
C3: 10uF; CP_Radial_D5.0mm_P2.00mm
C6: 0.33uF; C_Disc_D6.0mm_W4.4mm_P5.00mm
C12: 10uF; C_Disc_D5.1mm_W3.2mm_P5.00mm
C16: 15pF; C_Disc_D4.7mm_W2.5mm_P5.00mm
D1: 1N4148; D_DO-35_SOD27_P7.62mm_Horizontal
D2, D3: 1N4007; D_DO-41_SOD81_P10.16mm_Horizontal
D4, D5: LED; LED_D5.0mm_Clear
D6: IF E97; IF-E91A
F1: 500mA, 250V Fuse; 0PTF0078P
J1: 120/240VAC; SolderWire-1sqmm_1x02_P5.4mm_D1.4mm_OD2.7mm
J2: External Signal; CUI_TB007-508-02GR
J5, J6: Jumper; PinHeader_2x01_P2.54mm_Vertical
Q1: 2N3906; TO-92_Inline
Q2, Q3: 2N3904; TO-92_Inline
R1: 100k; R_Axial_DIN0309_L9.0mm_D3.2mm_P12.70mm_Horizontal
R2, R4, R6, R7, R9, R10, R11, R13, R14, R18: 10k; R_Axial_DIN0309_L9.0mm_D3.2mm_P12.70mm_Horizontal
R3, R5: 2.2k; R_Axial_DIN0309_L9.0mm_D3.2mm_P12.70mm_Horizontal
R8, R20: 4.7k; R_Axial_DIN0309_L9.0mm_D3.2mm_P12.70mm_Horizontal
R12, R16, R17: 1k; R_Axial_DIN0309_L9.0mm_D3.2mm_P12.70mm_Horizontal
R15: 330; R_Axial_DIN0309_L9.0mm_D3.2mm_P12.70mm_Horizontal
R19: 470; R_Axial_DIN0309_L9.0mm_D3.2mm_P12.70mm_Horizontal
RV1: 50k; SolderWire-0.5sqmm_1x03_P4.6mm_D0.9mm_OD2.1mm
RV2: 100k; SolderWire-0.5sqmm_1x03_P4.6mm_D0.9mm_OD2.1mm
SW1, SW2: SW_SPDT; SolderWire-0.5sqmm_1x03_P4.6mm_D0.9mm_OD2.1mm
SW3: SW_SP3T; SolderWire-0.5sqmm_1x04_P4.6mm_D0.9mm_OD2.1mm
T1: FS28-200-C2; TRANSFORMER_FS28-200-C2
U1: LM7812_TO220; TO-220-3_Vertical
U2, U3, U4: NE555P; DIP-8_W7.62mm

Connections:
GND1: C1.2, C2.2, C3.2, C5.2, C6.2, C8.2, C9.2, C11.2, C12.2, C13.2, C14.2, C15.2, D5.1 (K), D6.1 (K), J2.1, Q2.1 (E), Q3.1 (E), R1.2, R5.2, R7.2, R10.2, R13.2, SW2.3 (C), T1.6, T1.7, U1.2 (GND), U2.1 (GND), U3.1 (GND), U4.1 (GND)
unnamed: C1.1, C2.1, D2.1 (K), D3.1 (K), U1.1 (VI)
unnamed: C4.1, Q1.1 (E), R5.1
unnamed: C4.2, R6.2, R7.1, U2.2 (TR)
unnamed: C5.1, U2.5 (CV)
unnamed: C6.1, R8.2, U2.6 (THR), U2.7 (DIS)
unnamed: C7.1, R10.1, R11.2, U3.2 (TR)
unnamed: C7.2, U2.3 (Q)
unnamed: C8.1, U3.5 (CV)
unnamed: C9.1, R12.2, U3.6 (THR), U3.7 (DIS)
unnamed: C10.1, SW3.1, U3.3 (Q)
unnamed: C10.2, R13.1, R14.2, U4.2 (TR)
unnamed: C11.1, U4.5 (CV)
unnamed: C12.1, R15.2, U4.6 (THR), U4.7 (DIS)
unnamed: C3.1, C13.1, C14.1, C15.1, Q1.3 (C), R3.1, R6.1, R9.1, R11.1, R12.1, R14.1, R16.1, R17.1, R20.1, RV1.3, RV2.3, SW3.2, U1.3 (VO), U2.8 (VCC), U3.4 (R), U3.8 (VCC), U4.4 (R), U4.8 (VCC)
unnamed: C16.1, R19.1, SW2.2 (B)
unnamed: C16.2, D6.2 (A), R19.2, R20.2
unnamed: D1.1 (K), R2.1
unnamed: D1.2 (A), SW1.2 (B)
unnamed: D2.2 (A), SW1.1 (A), T1.5
unnamed: D3.2 (A), SW1.3 (C), T1.8
unnamed: D4.1 (K), R18.2, U4.3 (Q)
unnamed: D4.2 (A), R16.2
unnamed: D5.2 (A), R17.2
unnamed: F1.1, J1.2
unnamed: F1.2, J5.1, T1.1
unnamed: J1.1, J6.1, T1.4
unnamed: J2.2, SW3.4
unnamed: J5.2, T1.3
unnamed: J6.2, T1.2
unnamed: Q1.2 (B), R3.2, R4.1
unnamed: Q2.2 (B), R1.1, R2.2
unnamed: Q2.3 (C), R4.2
unnamed: Q3.2 (B), R18.1
unnamed: Q3.3 (C), R9.2, U2.4 (R)
unnamed: R8.1, RV1.1, RV1.2
unnamed: R15.1, RV2.1, RV2.2
unnamed: SW2.1 (A), SW3.3

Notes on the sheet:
All resistors are 1/2W unless otherwise indicated
ext in
gnd

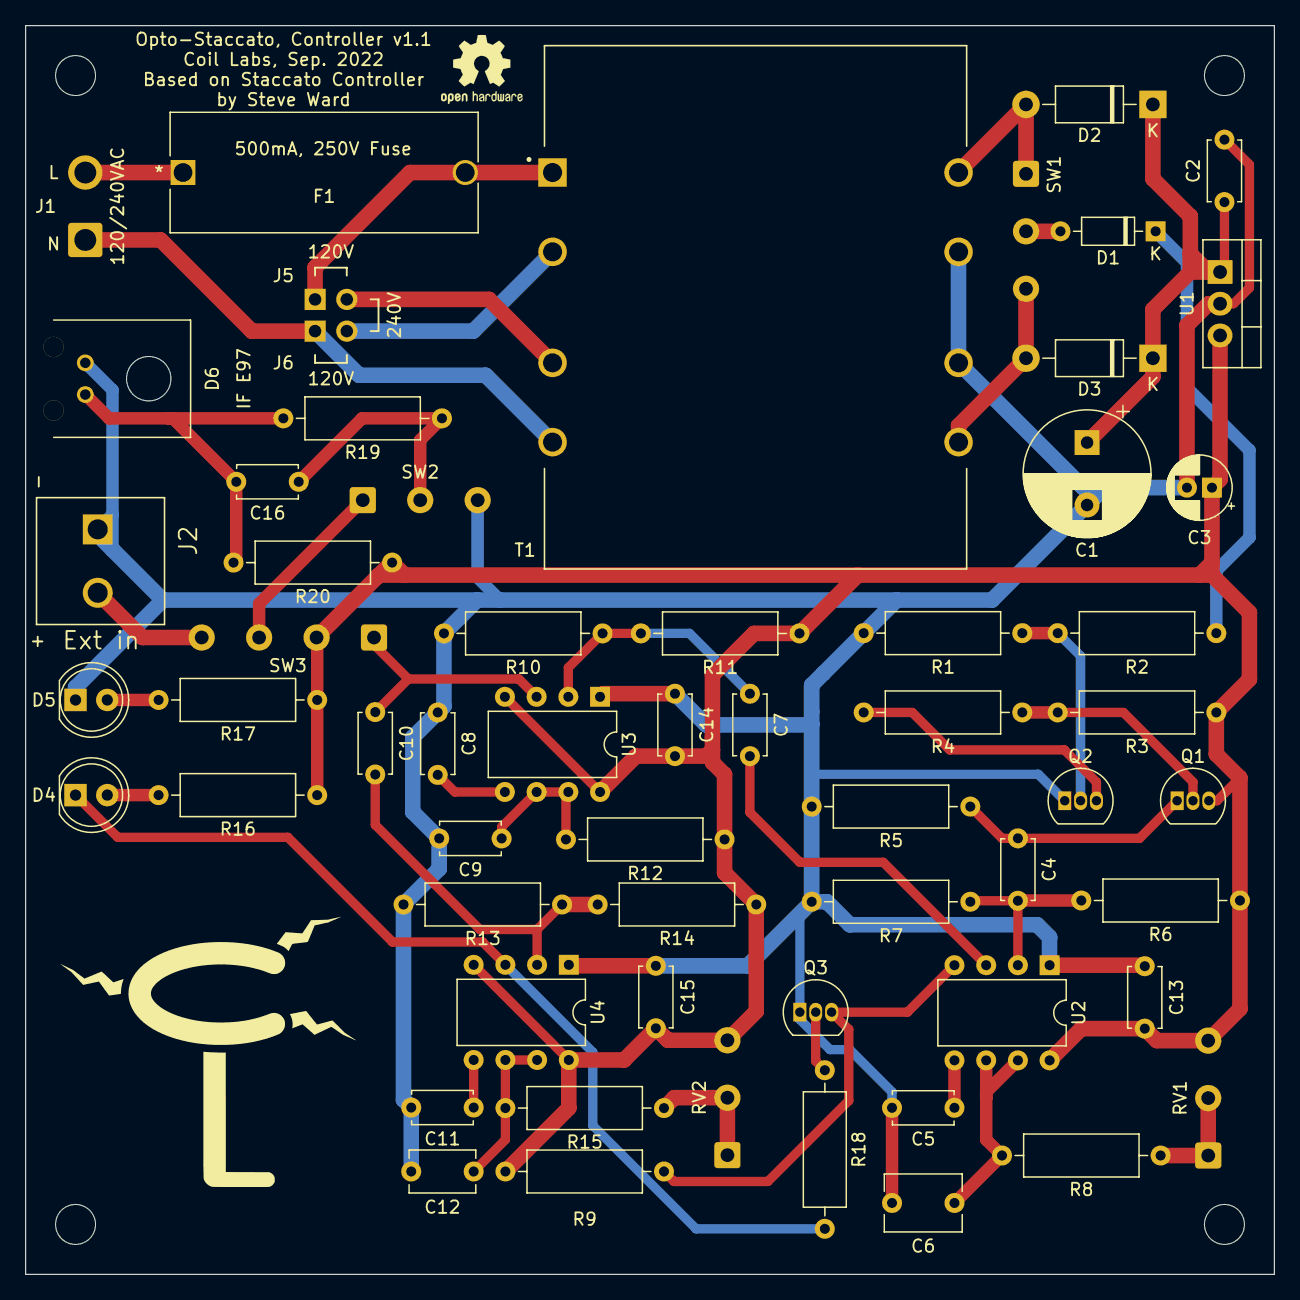
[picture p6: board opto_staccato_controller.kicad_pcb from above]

Board: 2 copper layers, 100.0 x 100.0 mm, 60 parts (0 on the bottom side), 38 nets.

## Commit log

2022-09-27 Add license to source files and images of schematics
    [opto_staccato_controller.kicad_sch, opto_staccato_receiver.kicad_sch]
2022-09-27 Add images of schematics to README
2022-09-28 Mention gerber files in releases in README

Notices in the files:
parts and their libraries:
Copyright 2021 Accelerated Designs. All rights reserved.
